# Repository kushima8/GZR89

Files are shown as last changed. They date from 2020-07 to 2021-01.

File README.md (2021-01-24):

# GZR89
left hand macro keyboards
EKI7KeYU4AAthqZ
# Build Guide
## GZR89C v1.0
[ビルドガイド（日本語）](GZR89C/Documents/buildguide_v1.0.md)
## GZR89D v1.0
[ビルドガイド（日本語）](GZR89D/Documents/buildguide_v1.0.md)

120px-Cc-by-nc-sa_icon svg

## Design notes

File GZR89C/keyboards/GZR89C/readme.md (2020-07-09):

# GZR89C

GZR89C

A short description of the keyboard/project

Keyboard Maintainer: [kushima8](https://github.com/yourusername)  
Hardware Supported: The PCBs, controllers supported  
Hardware Availability: links to where you can find this hardware

Make example for this keyboard (after setting up your build environment):

    make GZR89C:default

See the [build environment setup](https://docs.qmk.fm/#/getting_started_build_tools) and the [make instructions](https://docs.qmk.fm/#/getting_started_make_guide) for more information. Brand new to QMK? Start with our [Complete Newbs Guide](https://docs.qmk.fm/#/newbs).

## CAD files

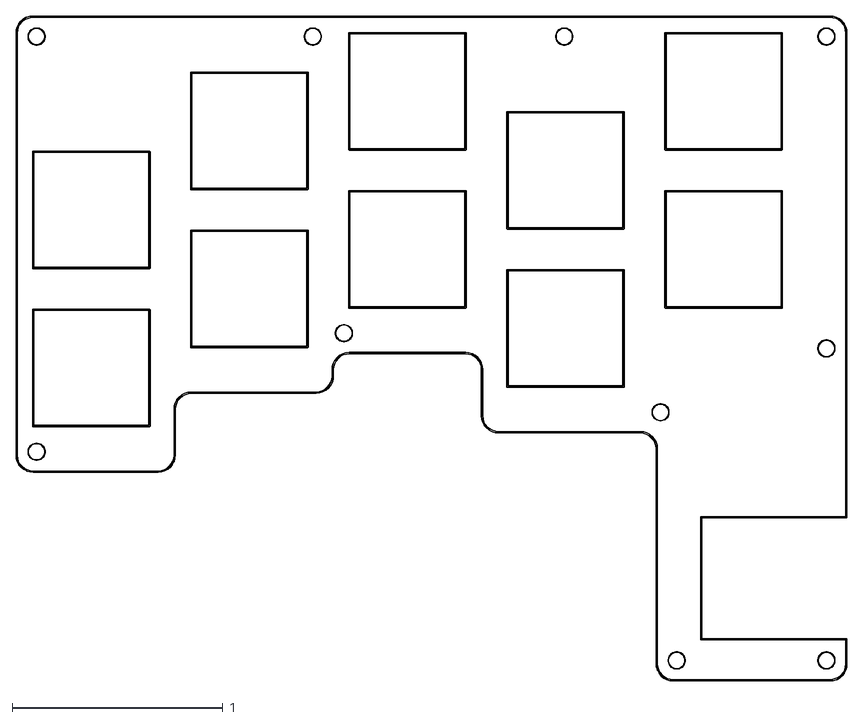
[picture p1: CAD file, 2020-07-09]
GZR89C/Plate/GZR89C_TopPlate.dxf
3.94 x 3.16

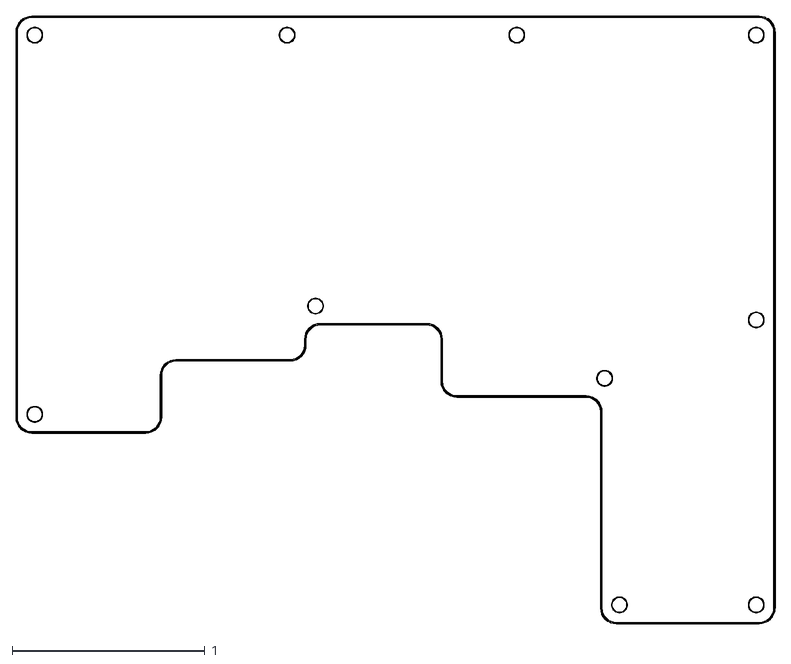
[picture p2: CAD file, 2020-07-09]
GZR89D/Plate/GZR89D_BottomPlate.dxf
3.94 x 3.16

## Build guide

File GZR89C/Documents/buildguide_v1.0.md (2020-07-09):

# GZR89C ver1.0 ビルドガイド
## はじめに
このたびはご購入いただきありがとうございます。<br>
本製品は組み立てが必要なキットです。<br>

ファームウェアに[qmk_firmware](https://github.com/qmk/qmk_firmware)を採用しております。<br>
キー割り当ての変更方法などはご自身でお調べいただくようお願いいたします。<br>

GZR89Cは8キー+プッシュスイッチ内蔵ＲＧＢＬＥＤ付ロータリーエンコーダの左手用マクロキーボードです。<br>
CLIP STUDIOやPhotoshopなどのグラフィックソフトなどで使用することを想定した設計となっております。<br>
ビルドガイド通りに作るとロータリーエンコーダが淡い青白っぽい色で光るよう調整してます。<br>
SK6812MINIによるバックライトに対応しています。<br>

## 部品

### キットに付属しているもの

|名称|数量|備考|
|----|:---:|----|
|PCB|2枚|緑色と黒色|
|トッププレート|1枚|
|スペーサー(3mm)|6個|
|スペーサー(6mm)|6個|
|ネジ(M2 4mm)|6個|
|ネジ(M2 8mm)|6個|
|タクトスイッチ|1個|
|ダイオード(1N4148)|8本|
|LEDチップ(SK6812MINI)|8個|
|カーボン抵抗(1/4Ｗ 330Ω)|1本|
|カーボン抵抗(1/4Ｗ 4.7kΩ)|1本|
|カーボン抵抗(1/4Ｗ 10kΩ)|2本|
|プッシュスイッチ内蔵ＲＧＢＬＥＤ付ロータリーエンコーダ|1個|
|透明つまみ|1個|**一度固定すると外れないので注意**|
|ジョグダイヤルツマミ|1個|33Φ 六角棒レンチを使い固定|
|六角棒レンチ|1本|
|ゴム足|6個|

### 別途、購入が必要なもの
以下の部品は別途購入してください。

|名称|数量|備考|
|----|:---:|----|
|キースイッチ(Cherry MX系)|8個|
|キーキャップ(Cherry MX系)|8個|
|Pro Micro|1個|
|コンスルーピンヘッダ	|2個|

## 組み立て
**※本製品には、黒と緑のPCBが封入されています。<br>
　黒のPCBを使用して実装を行ってください。<br>
　緑のPCBはボトムプレートとして使用します。<br>
 ※基盤製造の都合上、下部にバリが存在します。<br>
　気になる場合はヤスリなどで削ってください。**
* 表面<br>
　
* 裏面
　
* 1.Pro Microのはんだ付け
  * チップが載っている面が内側になるようにし、コンスルーピンヘッダを取り付けはんだ付けをしてください。
  * コンスルーピンヘッダには取り付け方向があるため気をつけてください。
  * [コンスルー - Self-Made Keyboards in Japan - ](https://scrapbox.io/self-made-kbds-ja/%E3%82%B3%E3%83%B3%E3%82%B9%E3%83%AB%E3%83%BC)
* 3.ファームウェアの書き込み
  * [GZR89C_test.hex](https://github.com/kushima8/GZR89/blob/master/GZR89C/HEX/GZR89C_test.hex)を指定してファームウェアを書き込んでください。
  * ファームウェアの書き込み手順については下記のサリチル酸さんのサイトを参考にしてください。
  * [（初心者編）自作キーボードにファームウェアを書き込む](https://salicylic-acid3.hatenablog.com/entry/qmk-toolbox)
* 4.LEDチップのはんだ付け(オプション)
  * LEDチップ(SK6812MINI)はPCBを裏面にして右上から左下、反転したZ字を書くように実装してください。
  * 調整はんだごてを約270℃に設定してはんだ付けをしてください。
  * 高い温度ではんだ付けを行うとLED破損の可能性があります。
  * LEDの向きに関しては下記画像を参考にしてください。<br>
  　
　　
  * はんだ付けが完了したら一度Pro Microを取り付け、LEDが光るかどうかテストを行ってください。
* 5.ダイオードのはんだ付け
  * ダイオードの足を曲げ、PCB前面から取り付け、裏面からはんだ付けを行ってください。
  * ダイオードの向きに関しては下記画像を参考にしてください。<br>
　　
* 6.カーボン抵抗のはんだ付け(オプション)
  * R1とR4に10kΩ、R2に4.7kΩ、R3に300Ωを足を折り曲げてPCB前面から取り付けてください。
  * その後、裏面からはんだ付けを行ってください。
  * カーボン抵抗の見分け方については下記サイトを参考にしてください。
  * [カラー抵抗値の写真早読み表！](http://part.freelab.jp/s_regi_list.html)
* 7.タクトスイッチのはんだ付け
  * PCB裏面から取り付け、表面からはんだ付けを行ってください。
* 8.トッププレートの取り付け
  * トッププレートの保護フィルムを剥がし、スペーサー(3mm)をネジ(M2 8mm)で固定してください。
  * その後、PCB表面に取り付け、サンドするようにスペーサー(6mm)を裏面から取り付けてください。
* 9.キースイッチのはんだ付け
  *  キースイッチをプレートに取り付け、PCB裏面からはんだ付けを行ってください。
* 10.ロータリーエンコーダのはんだ付け
  * ロータリーエンコーダを取り付け、PCB裏面からはんだ付けを行ってください。
* 11.Pro Microの取り付け
  * Pro Microを取り付け、キースイッチとロータリーエンコーダの入力の確認を行ってください。
  *　その後、[GZR89C_default.hex](https://github.com/kushima8/GZR89/blob/master/GZR89D/HEX/GZR89D_default.hex)を指定してファームウェアを書き込んでください。
  * defaultでのキーマップは以下の画像のようになっています。
  * Layer1<br>
  Layer1
  * Layer2<br>
  Layer2
* 12.ボトムプレートの取り付け
  * ボトムプレートとして緑色のPCBを使用します。
  * 裏面からネジ(M2 4mm)で固定してください。
* 13.ゴム足の取り付け
  * ボトムプレートにゴム足を取り付けください。

組み立ての手順は、以上です。

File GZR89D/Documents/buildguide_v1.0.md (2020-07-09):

# GZR89D ver1.0 ビルドガイド
## はじめに
このたびはご購入いただきありがとうございます。<br>
本製品は組み立てが必要なキットです。<br>

ファームウェアに[qmk_firmware](https://github.com/qmk/qmk_firmware)を採用しております。<br>
キー割り当ての変更方法などはご自身でお調べいただくようお願いいたします。<br>

GZR89Dは10キー+プッシュスイッチ内蔵ＲＧＢＬＥＤ付ロータリーエンコーダの左手用マクロキーボードです。<br>
CLIP STUDIOやPhotoshopなどのグラフィックソフトなどで使用することを想定した設計となっております。<br>
ビルドガイド通りに作るとロータリーエンコーダが淡い青白っぽい色で光るよう調整してます。<br>
SK6812MINIによるバックライトに対応しています。<br>

## 部品

### キットに付属しているもの

|名称|数量|備考|
|----|:---:|----|
|PCB|1枚|
|トッププレート|1枚|
|ボトムプレート|1枚|
|スペーサー(3mm)|10個|
|スペーサー(6mm)|10個|
|ネジ(M2 4mm)|10個|
|ネジ(M2 8mm)|10個|
|タクトスイッチ|1個|
|ダイオード(1N4148)|10本|
|LEDチップ(SK6812MINI)|10個|(オプション)|
|カーボン抵抗(1/4Ｗ 330Ω)|1本|
|カーボン抵抗(1/4Ｗ 4.7kΩ)|1本|
|カーボン抵抗(1/4Ｗ 10kΩ)|2本|
|プッシュスイッチ内蔵ＲＧＢＬＥＤ付ロータリーエンコーダ|1個|
|透明つまみ|1個|**一度固定すると外れないので注意**|
|ジョグダイヤルツマミ|1個|33Φ 六角棒レンチを使い固定|
|六角棒レンチ|1個|
|ゴム足|6個|

### 別途、購入が必要なもの
以下の部品は別途購入してください。

|名称|数量|備考|
|----|:---:|----|
|キースイッチ(Cherry MX系)|10個|
|キーキャップ(Cherry MX系)|10個|
|Pro Micro|1個|
|コンスルーピンヘッダ	|2個|

## 組み立て
* 表面<br>
　
* 裏面<br>
　
* 1.Pro Microのはんだ付け
  * チップが載っている面が内側になるようにし、コンスルーピンヘッダを取り付けはんだ付けをしてください。
  * コンスルーピンヘッダには取り付け方向があるため気をつけてください。
  * [コンスルー - Self-Made Keyboards in Japan - ](https://scrapbox.io/self-made-kbds-ja/%E3%82%B3%E3%83%B3%E3%82%B9%E3%83%AB%E3%83%BC)
* 3.ファームウェアの書き込み
  * [GZR89D_test.hex](https://github.com/kushima8/GZR89/blob/master/GZR89D/HEX/GZR89D_test.hex)を指定してファームウェアを書き込んでください。
  * ファームウェアの書き込み手順については下記のサリチル酸さんのサイトを参考にしてください。
  * [（初心者編）自作キーボードにファームウェアを書き込む](https://salicylic-acid3.hatenablog.com/entry/qmk-toolbox)
* 4.LEDチップのはんだ付け(オプション)
  * LEDチップ(SK6812MINI)はPCBを裏面にして右上から左下、反転したZ字を書くように実装してください。
  * 調整はんだごてを約270℃に設定してはんだ付けをしてください。
  * 高い温度ではんだ付けを行うとLED破損の可能性があります。
  * LEDの向きに関しては下記画像を参考にしてください。<br>
　　
　　
  * はんだ付けが完了したら一度Pro Microを取り付け、LEDが光るかどうかテストを行ってください。
* 5.ダイオードのはんだ付け
  * ダイオードの足を曲げ、PCB前面から取り付け、裏面からはんだ付けを行ってください。
  * ダイオードの向きに関しては下記画像を参考にしてください。<br>
　　
* 6.カーボン抵抗のはんだ付け
  * R1とR4に10kΩ、R2に4.7kΩ、R3に300Ωを足を折り曲げてPCB前面から取り付けてください。
  * その後、裏面からはんだ付けを行ってください。
  * カーボン抵抗の見分け方については下記サイトを参考にしてください。
  * [カラー抵抗値の写真早読み表！](http://part.freelab.jp/s_regi_list.html)
* 7.タクトスイッチのはんだ付け
  * PCB裏面から取り付け、表面からはんだ付けを行ってください。
* 8.トッププレートの取り付け
  * トッププレートの保護フィルムを剥がし、スペーサー(3mm)をネジ(M2 8mm)で固定してください。
  * その後、PCB表面に取り付け、サンドするようにスペーサー(6mm)を裏面から取り付けてください。
* 9.キースイッチのはんだ付け
  *  キースイッチをプレートに取り付け、PCB裏面からはんだ付けを行ってください。
* 10.ロータリーエンコーダのはんだ付け
  * ロータリーエンコーダを取り付け、PCB裏面からはんだ付けを行ってください。
* 11.Pro Microの取り付け
  * Pro Microを取り付け、キースイッチとロータリーエンコーダの入力の確認を行ってください。
  * その後、[GZR89D_default.hex](https://github.com/kushima8/GZR89/blob/master/GZR89D/HEX/GZR89D_default.hex)を指定してファームウェアを書き込んでください。
  * defaultでのキーマップは以下の画像のようになっています。
  * Layer1<br>
  Layer1
  * Layer2<br>
  Layer2
  * Layer3(バックライト操作用)<br>
  Layer3
* 12.ボトムプレートの取り付け
  * ボトムプレートの保護フィルムを剥がし、ネジ(M2 4mm)で固定してください。
* 13.ゴム足の取り付け
  * ボトムプレートにゴム足を取り付けください。

組み立ての手順は、以上です。

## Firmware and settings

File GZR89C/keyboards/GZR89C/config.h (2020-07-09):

/*
Copyright 2019 kushima8

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
You should have received a copy of the GNU General Public License
along with this program.  If not, see <http://www.gnu.org/licenses/>.
*/

#pragma once

#include "config_common.h"

/* USB Device descriptor parameter */
#define VENDOR_ID       0xFEED
#define PRODUCT_ID      0x0000
#define DEVICE_VER      0x0001
#define MANUFACTURER    kushima8
#define PRODUCT         GZR89C
#define DESCRIPTION     A custom keyboard

/* key matrix size */
#define MATRIX_ROWS 2
#define MATRIX_COLS 5

/*
 * Keyboard Matrix Assignments
 *
 * Change this to how you wired your keyboard
 * COLS: AVR pins used for columns, left to right
 * ROWS: AVR pins used for rows, top to bottom
 * DIODE_DIRECTION: COL2ROW = COL = Anode (+), ROW = Cathode (-, marked on diode)
 *                  ROW2COL = ROW = Anode (+), COL = Cathode (-, marked on diode)
 *
*/
#define MATRIX_ROW_PINS { D1, D0 }
#define MATRIX_COL_PINS { D4, F4, F5, F6, E6 }
#define UNUSED_PINS

/* COL2ROW, ROW2COL*/
#define DIODE_DIRECTION COL2ROW

/* Rotary encoder define*/
#define ENCODERS_PAD_A { F7 }
#define ENCODERS_PAD_B { B1 }

/*
 * Split Keyboard specific options, make sure you have 'SPLIT_KEYBOARD = yes' in your rules.mk, and define SOFT_SERIAL_PIN.
 */
//#define SOFT_SERIAL_PIN D0 // or D1, D2, D3, E6

#define BACKLIGHT_LED_COUNT 3
#undef BACKLIGHT_PIN
#define BACKLIGHT_PINS { C6, D7, B5 }
// #define BACKLIGHT_BREATHING
#define BACKLIGHT_LEVELS 3

#define RGB_DI_PIN D3
#ifdef RGB_DI_PIN
    #define RGBLED_NUM 8
//   #define RGBLIGHT_HUE_STEP 8
//   #define RGBLIGHT_SAT_STEP 8
//   #define RGBLIGHT_VAL_STEP 8
//   #define RGBLIGHT_LIMIT_VAL 255 /* The maximum brightness level */
//   #define RGBLIGHT_SLEEP  /* If defined, the RGB lighting will be switched off when the host goes to sleep */
// /*== all animations enable ==*/
    #define RGBLIGHT_ANIMATIONS
// /*== or choose animations ==*/
//   #define RGBLIGHT_EFFECT_BREATHING
//   #define RGBLIGHT_EFFECT_RAINBOW_MOOD
//   #define RGBLIGHT_EFFECT_RAINBOW_SWIRL
//   #define RGBLIGHT_EFFECT_SNAKE
//   #define RGBLIGHT_EFFECT_KNIGHT
//   #define RGBLIGHT_EFFECT_CHRISTMAS
//   #define RGBLIGHT_EFFECT_STATIC_GRADIENT
//   #define RGBLIGHT_EFFECT_RGB_TEST
//   #define RGBLIGHT_EFFECT_ALTERNATING
// /*== customize breathing effect ==*/
//   /*==== (DEFAULT) use fixed table instead of exp() and sin() ====*/
//   #define RGBLIGHT_BREATHE_TABLE_SIZE 256      // 256(default) or 128 or 64
//   /*==== use exp() and sin() ====*/
//   #define RGBLIGHT_EFFECT_BREATHE_CENTER 1.85  // 1 to 2.7
//   #define RGBLIGHT_EFFECT_BREATHE_MAX    255   // 0 to 255
#endif

/* Debounce reduces chatter (unintended double-presses) - set 0 if debouncing is not needed */
#define DEBOUNCE 5

/* define if matrix has ghost (lacks anti-ghosting diodes) */
//#define MATRIX_HAS_GHOST

/* Mechanical locking support. Use KC_LCAP, KC_LNUM or KC_LSCR instead in keymap */
#define LOCKING_SUPPORT_ENABLE
/* Locking resynchronize hack */
#define LOCKING_RESYNC_ENABLE

/* If defined, GRAVE_ESC will always act as ESC when CTRL is held.
 * This is userful for the Windows task manager shortcut (ctrl+shift+esc).
 */
// #define GRAVE_ESC_CTRL_OVERRIDE

/*
 * Force NKRO
 *
 * Force NKRO (nKey Rollover) to be enabled by default, regardless of the saved
 * state in the bootmagic EEPROM settings. (Note that NKRO must be enabled in the
 * makefile for this to work.)
 *
 * If forced on, NKRO can be disabled via magic key (default = LShift+RShift+N)
 * until the next keyboard reset.
 *
 * NKRO may prevent your keystrokes from being detected in the BIOS, but it is
 * fully operational during normal computer usage.
 *
 * For a less heavy-handed approach, enable NKRO via magic key (LShift+RShift+N)
 * or via bootmagic (hold SPACE+N while plugging in the keyboard). Once set by
 * bootmagic, NKRO mode will always be enabled until it is toggled again during a
 * power-up.
 *
 */
//#define FORCE_NKRO

/*
 * Magic Key Options
 *
 * Magic keys are hotkey commands that allow control over firmware functions of
 * the keyboard. They are best used in combination with the HID Listen program,
 * found here: https://www.pjrc.com/teensy/hid_listen.html
 *
 * The options below allow the magic key functionality to be changed. This is
 * useful if your keyboard/keypad is missing keys and you want magic key support.
 *
 */

/* key combination for magic key command */
/* defined by default; to change, uncomment and set to the combination you want */
// #define IS_COMMAND() (get_mods() == MOD_MASK_SHIFT)

/* control how magic key switches layers */
//#define MAGIC_KEY_SWITCH_LAYER_WITH_FKEYS  true
//#define MAGIC_KEY_SWITCH_LAYER_WITH_NKEYS  true
//#define MAGIC_KEY_SWITCH_LAYER_WITH_CUSTOM false
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

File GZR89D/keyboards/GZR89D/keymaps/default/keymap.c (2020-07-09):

/* Copyright 2019 kushima8
 *
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
 * You should have received a copy of the GNU General Public License
 * along with this program.  If not, see <http://www.gnu.org/licenses/>.
 */
#include QMK_KEYBOARD_H

enum layer_number {
    _FIRST = 0,
    _SECOND,
    _THIRD
};

#define FIRST TO(_FIRST)
#define SECOND TO(_SECOND)
#define THIRD TO(_THIRD)

const uint16_t PROGMEM keymaps[][MATRIX_ROWS][MATRIX_COLS] = {
    [_FIRST] = LAYOUT(
        LCTL(KC_S), LCTL(KC_LALT), KC_C,         KC_LALT, THIRD,
        LCTL(KC_Z), LCTL(KC_Y),    LALT(KC_SPC), KC_SPC,  SECOND, RGB_TOG
    ),
    [_SECOND] = LAYOUT(
        KC_P,             KC_E,       KC_G,             KC_M,       THIRD,
        LSFT(LCTL(KC_T)), LCTL(KC_U), LSFT(LCTL(KC_N)), LCTL(KC_E), FIRST, RGB_TOG
    ),
    [_THIRD] = LAYOUT(
        RGB_HUI, RGB_SAI, RGB_VAI, RGB_MOD,  FIRST,
        RGB_HUD, RGB_SAD, RGB_VAD, RGB_RMOD, SECOND, RGB_TOG
    ),
};

/* Rotary encoder settings */
void encoder_update_user(uint16_t index, bool clockwise) {
    switch(biton32(layer_state)) {
        case _FIRST:
            if (clockwise) {
                tap_code16(KC_QUOT);    //Rotary encoder clockwise
            } else {
                tap_code16(KC_MINS);    //Rotary encoder Reverse clockwise
            }
            break;
        case _SECOND:
            if (clockwise) {
                tap_code16(KC_RBRC);    //Rotary encoder clockwise
            } else {
                tap_code16(KC_LBRC);    //Rotary encoder Reverse clockwise
            }
            break;
        case _THIRD:
            if (clockwise) {
                tap_code16(KC_UP);      //Rotary encoder clockwise
            } else {
                tap_code16(KC_DOWN);    //Rotary encoder Reverse clockwise
            }
            break;
    }
}

uint32_t layer_state_set_user(uint32_t state) {
    switch (biton32(state)) {
        case _FIRST:
            wait_ms(100);
            rgblight_sethsv(rgblight_get_hue(),rgblight_get_sat(),rgblight_get_val());
            break;
        case _SECOND:
            wait_ms(100);
            rgblight_sethsv(rgblight_get_hue(),rgblight_get_sat(),rgblight_get_val());
            rgblight_setrgb_at(RGB_RED,9);
            break;
        case _THIRD:
            wait_ms(100);
            rgblight_sethsv(rgblight_get_hue(),rgblight_get_sat(),rgblight_get_val());
            rgblight_setrgb_at(RGB_BLUE,4);
            break;
    }
    return state;
}

void matrix_init_user(void) {

}

void matrix_scan_user(void) {

}

void led_set_user(uint8_t usb_led) {

}

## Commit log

2020-07-09 add GZR89
    [GZR89C-B_Cu.gbr, GZR89C-B_Mask.gbr, GZR89C-B_SilkS.gbr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]
2020-08-01 Update FolderName
    [GZR89C_TopPlate.dxf, GZR89D_BottomPlate.dxf, GZR89D_TopPlate.dxf]

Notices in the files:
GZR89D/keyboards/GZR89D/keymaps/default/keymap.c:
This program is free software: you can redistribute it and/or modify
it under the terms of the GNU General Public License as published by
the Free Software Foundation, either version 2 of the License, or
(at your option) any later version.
